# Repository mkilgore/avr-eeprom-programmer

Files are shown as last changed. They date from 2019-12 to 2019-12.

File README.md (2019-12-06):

ATMega328P EEPROM Programmer
============================

This is a simple EEPROM programmer, designed to program the AM29F040B chip.
This project is fully functional at this stage, and includes three distinct
parts:

1. board
  - This is the schematic and PCB layout for the programmer. It uses an
    ATMega328P along with two shift registers to talk to the AM29F040B. It also
    includes a PLCC32 socket for the AM29F040B, a few LEDs for indicating
    read/write, and a serial in/out for talking to the programmer.

1. driver
  - This is the code that runs on the ATMega328P chip and executes the read/write
    commands against the AM29F040B chip.

3. programmer
  - This sends commands to the driver over a serial connection and tells it to
    either read, write, or erase the chip.

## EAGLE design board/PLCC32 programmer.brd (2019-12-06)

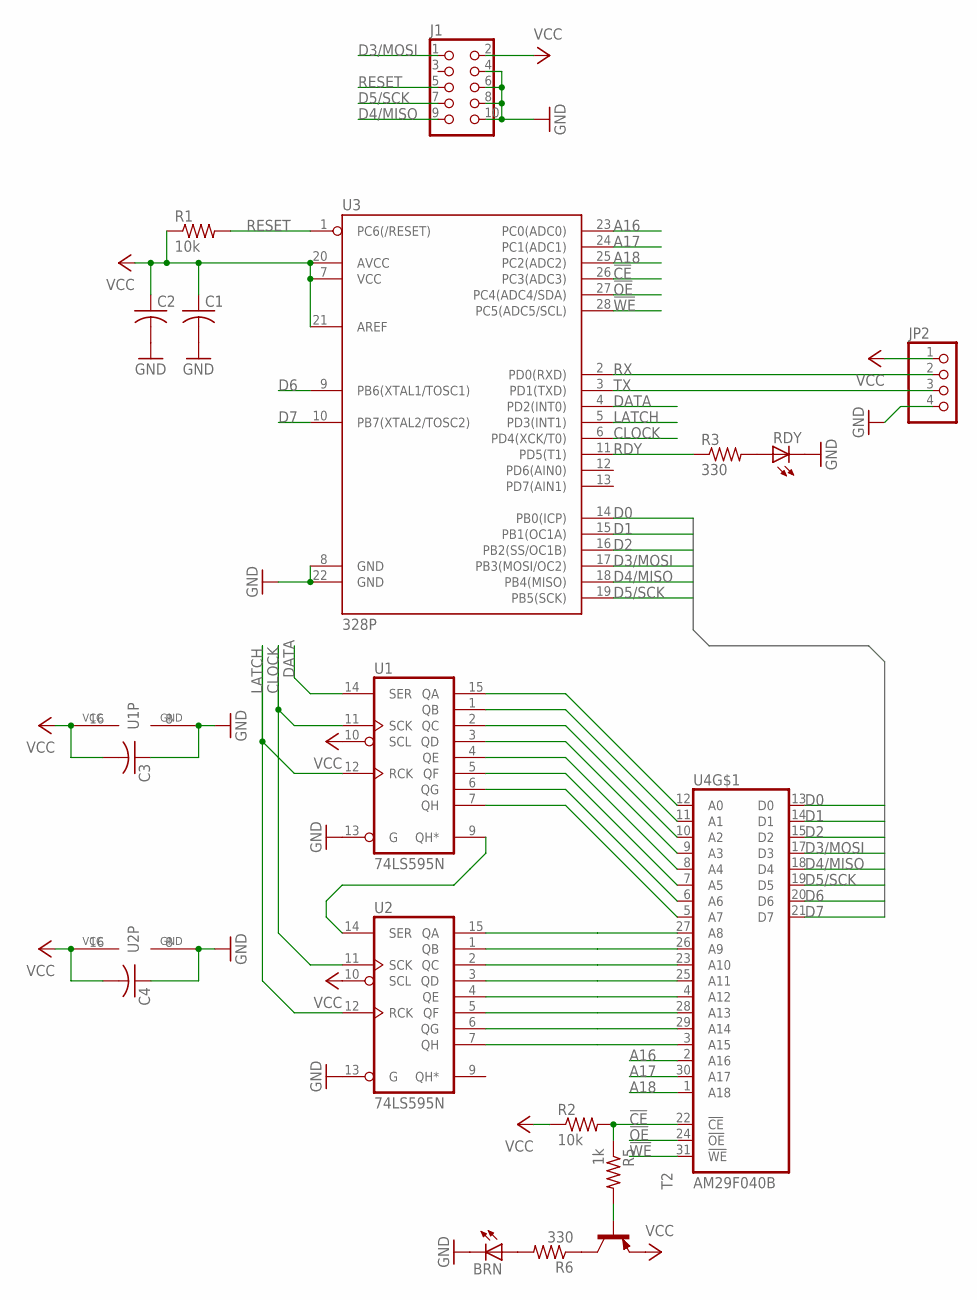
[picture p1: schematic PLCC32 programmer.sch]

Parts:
BRN: LED5MM
C1, C2, C3, C4: C-US025-024X044; C025-024X044
J1: CON_HEADER_2X05-PTH+SHROUDED_A; PINSHRD_PTH_2X05
JP2: PINHD-1X4/OCT; 1X04/OCT
R1, R2: 10k; 0204/7
R3, R6: 330; 0204/7
R5: 1k; 0204/7
RDY: LED5MM
T2: BC558A-PNP-TO92-EBC; TO92-EBC
U1, U2: 74LS595N; DIL16
U3: 328P; DIP28
U4: AM29F040B; PLCC-32-SMT-TT

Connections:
!CE: R2.2, R5.1, U3.26 (PC3(ADC3)), U4.22 (!CE)
!OE: U3.27 (PC4(ADC4/SDA)), U4.24 (!OE)
!WE: U3.28 (PC5(ADC5/SCL)), U4.31 (!WE)
A16: U3.23 (PC0(ADC0)), U4.2 (A16)
A17: U3.24 (PC1(ADC1)), U4.30 (A17)
A18: U3.25 (PC2(ADC2)), U4.1 (A18)
CLOCK: U1.11 (SCK), U2.11 (SCK), U3.6 (PD4(XCK/T0))
D0: U3.14 (PB0(ICP)), U4.13 (D0)
D1: U3.15 (PB1(OC1A)), U4.14 (D1)
D2: U3.16 (PB2(SS/OC1B)), U4.15 (D2)
D3/MOSI: J1.1, U3.17 (PB3(MOSI/OC2)), U4.17 (D3)
D4/MISO: J1.9, U3.18 (PB4(MISO)), U4.18 (D4)
D5/SCK: J1.7, U3.19 (PB5(SCK)), U4.19 (D5)
D6: U3.9 (PB6(XTAL1/TOSC1)), U4.20 (D6)
D7: U3.10 (PB7(XTAL2/TOSC2)), U4.21 (D7)
DATA: U1.14 (SER), U3.4 (PD2(INT0))
GND: BRN.K (C), C1.2, C2.2, C3.1, C4.1, J1.4, J1.6, J1.8, J1.10, JP2.4, RDY.K (C), U1.8 (GND), U1.13 (G), U2.8 (GND), U2.13 (G), U3.8 (GND), U3.22 (GND), U4.16 (GND)
LATCH: U1.12 (RCK), U2.12 (RCK), U3.5 (PD3(INT1))
unnamed: U1.9 (QH*), U2.14 (SER)
unnamed: U1.15 (QA), U4.12 (A0)
unnamed: U1.1 (QB), U4.11 (A1)
unnamed: U1.2 (QC), U4.10 (A2)
unnamed: U1.3 (QD), U4.9 (A3)
unnamed: U1.4 (QE), U4.8 (A4)
unnamed: U1.5 (QF), U4.7 (A5)
unnamed: U1.6 (QG), U4.6 (A6)
unnamed: U1.7 (QH), U4.5 (A7)
unnamed: U2.15 (QA), U4.27 (A8)
unnamed: U2.1 (QB), U4.26 (A9)
unnamed: U2.2 (QC), U4.23 (A10)
unnamed: U2.3 (QD), U4.25 (A11)
unnamed: U2.4 (QE), U4.4 (A12)
unnamed: U2.5 (QF), U4.28 (A13)
unnamed: U2.6 (QG), U4.29 (A14)
unnamed: U2.7 (QH), U4.3 (A15)
unnamed: R3.2, RDY.A
unnamed: R6.1, T2.C
unnamed: BRN.A, R6.2
unnamed: R5.2, T2.B
RDY: R3.1, U3.11 (PD5(T1))
RESET: J1.5, R1.2, U3.1 (PC6(/RESET))
RX: JP2.2, U3.2 (PD0(RXD))
TX: JP2.3, U3.3 (PD1(TXD))
VCC: C1.1, C2.1, C3.2, C4.2, J1.2, JP2.1, R1.1, R2.1, T2.E, U1.10 (SCL), U1.16 (VCC), U2.10 (SCL), U2.16 (VCC), U3.7 (VCC), U3.20 (AVCC), U3.21 (AREF), U4.32 (VCC)

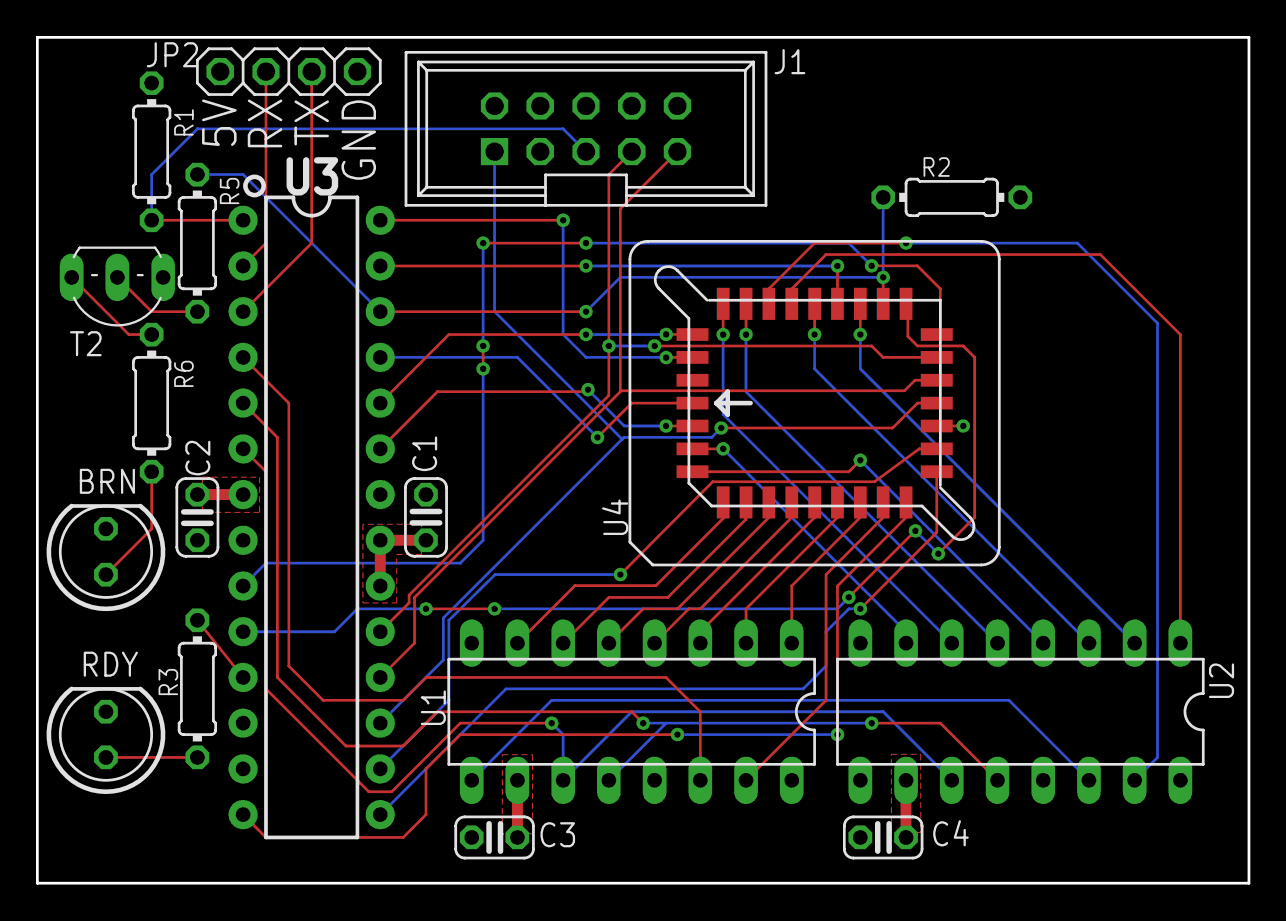
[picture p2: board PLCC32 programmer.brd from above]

Board: 2 copper layers, 67.3 x 47.0 mm, 18 parts (0 on the bottom side), 44 nets.

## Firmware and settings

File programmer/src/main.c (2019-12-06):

#include "common.h"

#include <stdio.h>
#include <stdlib.h>
#include <string.h>

#include "list.h"
#include "eeprom_tty.h"
#include "msg_handler.h"
#include "arg_parser.h"
#include "cmd.h"

static const char *version_text = "eepgmr-" Q(VER_MAJOR) "." Q(VER_MINOR) "." Q(VER_PATCH);

static const char *arg_str = "[Flags] tty-device";
static const char *usage_str = "Write and read data from an AVR EEPROM Programmer.\n";
static const char *arg_desc_str  = "";

#define XARGS \
    X(read, "read", 'r', 1, "address:length", "Read bytes from EEPROM and display to console") \
    X(readfile, "read-to-file", 'R', 1, "address:file", "Read bytes from EEPROM to file") \
    X(compare, "compare-to-file", 'c', 1, "address[:length][:offset]:filename", "Compare bytes from EEPROM to file contents") \
    X(write, "write", 'w', 1, "address[:length][:offset]:filename", "Write bytes to EEPROM") \
    X(erase_sector, "erase-sector", 's', 1, "number", "Erase sector from EEPROM") \
    X(erase_chip, "erase-chip", 'e', 0, NULL, "Erase full EEPROM chip") \
    X(baud, "baud", 'b', 1, "baudrate", "Specify the baud rate the programmer communicates at") \
    X(help, "help", 'h', 0, NULL, "Display help") \
    X(version, "version", 'v', 0, NULL, "Display version information") \
    X(last, NULL, '\0', 0, NULL, NULL)

enum arg_index {
    ARG_EXTRA = ARG_PARSER_EXTRA,
    ARG_ERR = ARG_PARSER_ERR,
    ARG_DONE = ARG_PARSER_DONE,
#define X(enu, id, arg, op, arg_text, help_text) ARG_##enu,
    XARGS
#undef X
};

static const struct arg ls_args[] = {
#define X(enu, id, op, arg, arg_text, help_text) CREATE_ARG(enu, id, op, arg, arg_text, help_text)
    XARGS
#undef X
};

struct cmd_def {
    enum cmd_type type;
    int (*init) (struct cmd *, const char *);
} cmd_defs[] = {
    [ARG_read] = { .type = CMD_READ, .init = cmd_parse_read },
    [ARG_readfile] = { .type = CMD_READ_FILE, .init = cmd_parse_read_file },
    [ARG_compare] = { .type = CMD_READ_COMPARE_FILE, .init = cmd_parse_read_compare_file },
    [ARG_write] = { .type = CMD_WRITE, .init = cmd_parse_write },
    [ARG_erase_sector] = { .type = CMD_ERASE_SECTOR, .init = cmd_parse_erase_sector },
    [ARG_erase_chip] = { .type = CMD_ERASE_CHIP, .init = NULL },
};

static list_head_t cmd_list = LIST_HEAD_INIT(cmd_list);
static const char *tty_device;
static speed_t baudrate;
static int set_baudrate = 0;

static int cmd_add(enum cmd_type type, int (*init) (struct cmd *, const char *), const char *arg)
{
    struct cmd *cmd = malloc(sizeof(*cmd));
    cmd_init(cmd);

    if (init && init(cmd, arg))
        return 1;

    cmd->type = type;
    list_add_tail(&cmd_list, &cmd->node);
    return 0;
}

int main(int argc, char **argv)
{
    enum arg_index ret;
    struct cmd *cmd;

    while ((ret = arg_parser(argc, argv, ls_args)) != ARG_DONE) {
        switch (ret) {
        case ARG_help:
            display_help_text(argv[0], arg_str, usage_str, arg_desc_str, ls_args);
            return 0;

        case ARG_version:
            printf("%s\n", version_text);
            return 0;

        case ARG_read:
        case ARG_readfile:
        case ARG_compare:
        case ARG_write:
        case ARG_erase_sector:
        case ARG_erase_chip:
            if (cmd_add(cmd_defs[ret].type, cmd_defs[ret].init, argarg))
                return 1;

            break;

        case ARG_baud:
            baudrate = atol(argarg);
            set_baudrate = 1;
            break;

        case ARG_EXTRA:
            if (!tty_device) {
                tty_device = argarg;
            } else {
                printf("%s: Unexpected argument '%s'\n", argv[0], argarg);
                return 1;
            }
            break;

        default:
            return 1;
        }
    }

    if (!tty_device) {
        printf("%s: Please specify a TTY device.\n", argv[0]);
        return 1;
    }

    struct eeprom_tty tty;
    memset(&tty, 0, sizeof(tty));

    eeprom_tty_open(&tty, tty_device);

    if (set_baudrate)
        eeprom_tty_set_baud(&tty, baudrate);

    struct msg_handler_state msg_state;
    memset(&msg_state, 0, sizeof(msg_state));

    msg_state.tty = &tty;
    printf("Resetting TTY stream...\n");
    msg_reset_stream(&msg_state);

    list_foreach_entry(&cmd_list, cmd, node)
        if (cmd_exec(cmd, &msg_state))
            break;

    eeprom_tty_close(&tty);

    return 0;
}

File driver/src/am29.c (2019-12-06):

#include "common.h"

#include <stdio.h>
#include <stdint.h>
#include <string.h>

#include "shift.h"
#include "am29.h"

struct shift_register address_low_16 = {
    .data_port = &PORTD,
    .data_pin = PORTD2,

    .latch_port = &PORTD,
    .latch_pin = PORTD3,

    .clock_port = &PORTD,
    .clock_pin = PORTD4,
};

#define CE_PIN PORTC3
#define OE_PIN PORTC4
#define WE_PIN PORTC5

static void am29_data_set_as_input(void)
{
    DDRB = 0;
    PORTB = 0xF0;
    _delay_ms(1);
}

static void am29_data_set_as_output(void)
{
    DDRB = 0xFF;
}

static void am29_setup_address(void)
{
    /* Turn on shift register outputs */
    DDRD |= 0b00011100;

    /* Turn on extra high 3 bits of address */
    DDRC |= 0x07;
}

static void am29_setup_control_lines(void)
{
    DDRC |= 0b00111000;
}

static void am29_teardown_gpio(void)
{
    DDRB = 0;
    DDRD &= ~0b00011100;
    DDRC &= ~0b00111111;
}

void am29_start(void)
{
    am29_setup_address();
    am29_setup_control_lines();
}

void am29_finish(void)
{
    am29_teardown_gpio();
}

static uint8_t am29_get_sector(uint32_t addr)
{
    return (addr & 0x70000) >> 16;
}

static uint16_t am29_get_addr(uint32_t addr)
{
    return addr & 0xFFFF;
}

/* Note: All of these 'enable' and 'disable' lines are active low */
static void am29_ce_enable(void)
{
    cbi(PORTC, CE_PIN);
}

static void am29_ce_disable(void)
{
    sbi(PORTC, CE_PIN);
}

static void am29_we_enable(void)
{
    cbi(PORTC, WE_PIN);
}

static void am29_we_disable(void)
{
    sbi(PORTC, WE_PIN);
}

static void am29_oe_enable(void)
{
    cbi(PORTC, OE_PIN);
}

static void am29_oe_disable(void)
{
    sbi(PORTC, OE_PIN);
}

static void am29_set_address(uint8_t sector, uint16_t addr)
{
    shift_register_write_byte(&address_low_16, addr >> 8);
    shift_register_write_byte(&address_low_16, addr & 0xFF);
    shift_register_latch_output(&address_low_16);

    PORTC &= ~0x07;
    PORTC |= sector & 0x07;
}

static uint8_t am29_read_byte_internal(uint8_t sector, uint16_t addr)
{
    uint8_t data;
    am29_set_address(sector, addr);
    am29_data_set_as_input();

    am29_ce_enable();
    am29_oe_enable();
    _delay_us(1);
    data = PINB;
    am29_oe_disable();
    am29_ce_disable();

    return data;
}

static void am29_write_byte_internal(uint8_t sector, uint16_t addr, uint8_t data)
{
    am29_set_address(sector, addr);
    am29_data_set_as_output();
    PORTB = data;

    am29_ce_enable();
    am29_we_enable();
    _delay_us(0.3);
    am29_we_disable();
    _delay_us(0.3);
    am29_ce_disable();
}

static void am29_program_byte(uint8_t sector, uint16_t addr, uint8_t data)
{
    am29_write_byte_internal(0, 0x555, 0xAA);
    am29_write_byte_internal(0, 0x2AA, 0x55);
    am29_write_byte_internal(0, 0x555, 0xA0);
    am29_write_byte_internal(sector, addr, data);
}

/* Returns zero on success, non-zero on failure */
static int verify_write(uint8_t sector, uint16_t addr, uint8_t data)
{
    uint8_t b1, b2;

    while (1) {
        b1 = am29_read_byte_internal(sector, addr);
        b2 = am29_read_byte_internal(sector, addr);

        /* (1 << 6) is the toggle bit, If it didn't toggle, then the operation is complete */
        if ((b1 & (1 << 6)) == (b2 & (1 << 6))) {
            return !(b1 == data);
        }

        /* Check if the time-limit has expired */
        if (b1 & (1 << 5)) {
            b1 = am29_read_byte_internal(sector, addr);
            b2 = am29_read_byte_internal(sector, addr);
            if ((b1 & (1 << 6)) == (b2 & (1 << 6)))
                return !(b1 == data);
            else
                return 1;
        }
    }
}

int am29_erase_chip(void)
{
    am29_write_byte_internal(0, 0x555, 0xAA);
    am29_write_byte_internal(0, 0x2AA, 0x55);
    am29_write_byte_internal(0, 0x555, 0x80);
    am29_write_byte_internal(0, 0x555, 0xAA);
    am29_write_byte_internal(0, 0x2AA, 0x55);
    am29_write_byte_internal(0, 0x555, 0x10);

    return verify_write(0, 0, 0xFF);
}

int am29_erase_sector(uint8_t sector)
{
    am29_write_byte_internal(0, 0x555, 0xAA);
    am29_write_byte_internal(0, 0x2AA, 0x55);
    am29_write_byte_internal(0, 0x555, 0x80);
    am29_write_byte_internal(0, 0x555, 0xAA);
    am29_write_byte_internal(0, 0x2AA, 0x55);
    am29_write_byte_internal(0, ((uint16_t)sector << 8) | 0xA, 0x30);

    return verify_write(sector, 0, 0xFF);
}

int am29_write_byte(uint32_t addr32, uint8_t data)
{
    uint8_t sector = am29_get_sector(addr32);
    uint16_t addr = am29_get_addr(addr32);

    int i;

    for (i = 0; i < 5; i++) {
        am29_program_byte(sector, addr, data);

        if (verify_write(sector, addr, data))
            return 1;
    }

    return 0;
}

uint8_t am29_read_byte(uint32_t addr)
{
    return am29_read_byte_internal(am29_get_sector(addr), am29_get_addr(addr));
}

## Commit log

2018-09-30 Initial code for EEPROM programmer and driver
2019-12-06 Fix up programmer code
    [main.c]
2019-12-06 driver improvements
2019-12-06 add board sch and brd files
    [PLCC32 programmer.brd, PLCC32 programmer.sch]

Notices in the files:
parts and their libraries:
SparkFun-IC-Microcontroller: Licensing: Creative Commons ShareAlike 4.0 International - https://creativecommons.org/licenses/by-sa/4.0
